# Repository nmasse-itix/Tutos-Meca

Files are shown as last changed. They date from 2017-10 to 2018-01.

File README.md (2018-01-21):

# Tutos mécanique
## Renault Avantime
### Trains roulants
- [Remplacement des triangles](Renault-Avantime/Remplacement-des-triangles/README.md)

### Habitacle
- [Démonter les panneaux de porte](Renault-Avantime/Demontage-des-panneaux-de-porte/README.md)
- [Réparation de la serrure, portière conducteur](Renault-Avantime/Reparation-de-la-serrure/README.md)

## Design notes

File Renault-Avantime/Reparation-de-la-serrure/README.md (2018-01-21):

# Réparation de la serrure de portière d'une Renault Avantime

## Symptômes

Parfois lorsque la télécommande qui permet de verrouiller/déverrouiller les portes
tombe en panne, plutôt que de faire réparer la télécommande, on utilise la serrure
pour ouvrir la portière.

Hé bien, c'est une bien mauvaise idée !

La serrure de l'avantime a l'air plutôt fragile de conception et pourrait bien vous
lâcher un jour ou l'autre.

Lorsque la serrure casse, le barillet vous reste dans les mains avec la clé et si
la serrure n'est pas déverrouillée, il n'est plus possible d'ouvrir la portière.

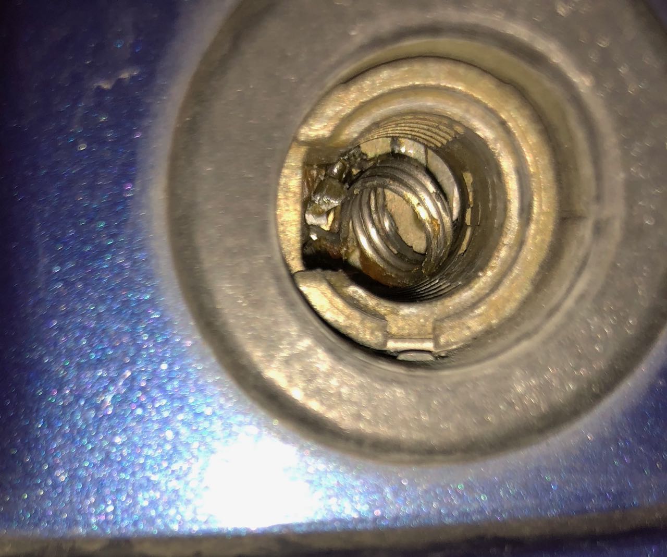
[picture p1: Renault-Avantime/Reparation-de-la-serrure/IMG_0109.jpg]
Voici ce qu'il reste de la serrure


Si vous avez encore la télécommande, ouvrez la portière avec celle-ci. Dans le cas
contraire, il faut ouvrir la portière comme le ferait un voleur...

Si heureusement la portière s'est déverrouillée avant de casser, vous avez de la
chance, il vous suffira de la réparer !

Le barillet ressemble à ça :

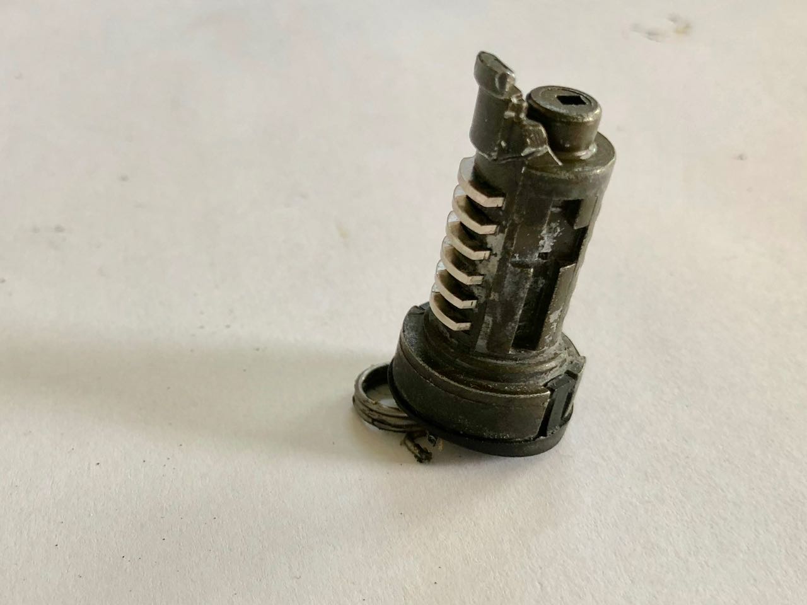
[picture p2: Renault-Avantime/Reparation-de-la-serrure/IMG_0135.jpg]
Le barillet


La petite pièce qui entraîne le mécanisme de la serrure est cassée :

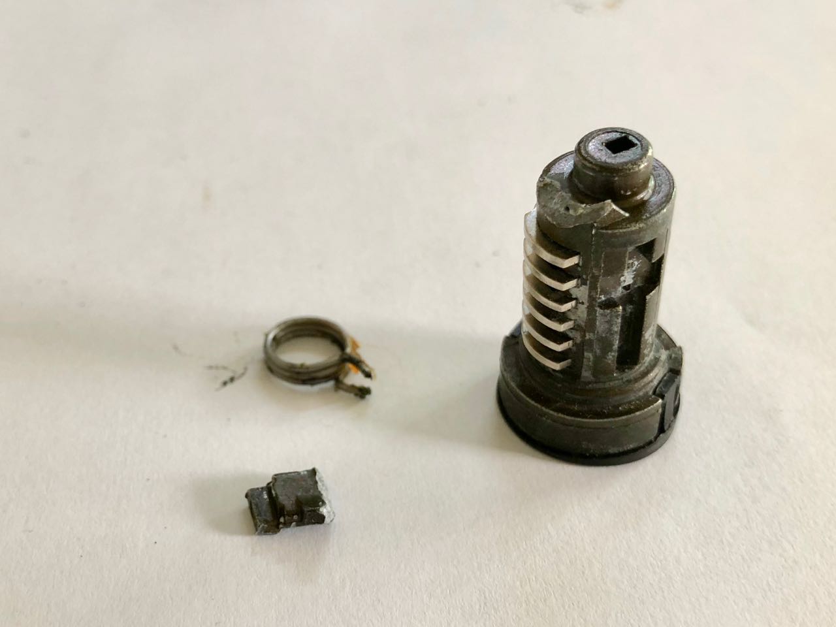
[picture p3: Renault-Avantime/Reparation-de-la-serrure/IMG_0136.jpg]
Le barillet cassé


## Matériel nécessaire

En plus du matériel nécessaire pour [démonter les panneaux de porte](../Demontage-des-panneaux-de-porte/README.md), il vous faudra :

- une Dremel
- une lime
- un pied à coulisse
- un marqueur fin
- un petit tournevis
- une pince à ressort pour tenir les pièces pendant le collage
- une toute petite pince étau pour tenir les pièces pendant le collage (ou pince équivalente)

## Liste des consommables à acheter

- de la colle bi-composant, type Araldite ou [Cyanolit Puissance +](https://www.cyanolit-colles.com/produits/colle-puissance-plus/).
- de l'huile grafitée pour serrures
- une bombe de nettoyant frein

## 1. Démontage

### 1.1. Démonter les panneaux de porte

[Démonter les panneaux de porte en suivant les instructions ici](../Demontage-des-panneaux-de-porte/README.md).

### 1.2. Démonter la platine qui tient la serrure

Une fois les panneaux de porte démontés, il faut enlever la vis qui tient la platine noire de la serrure.

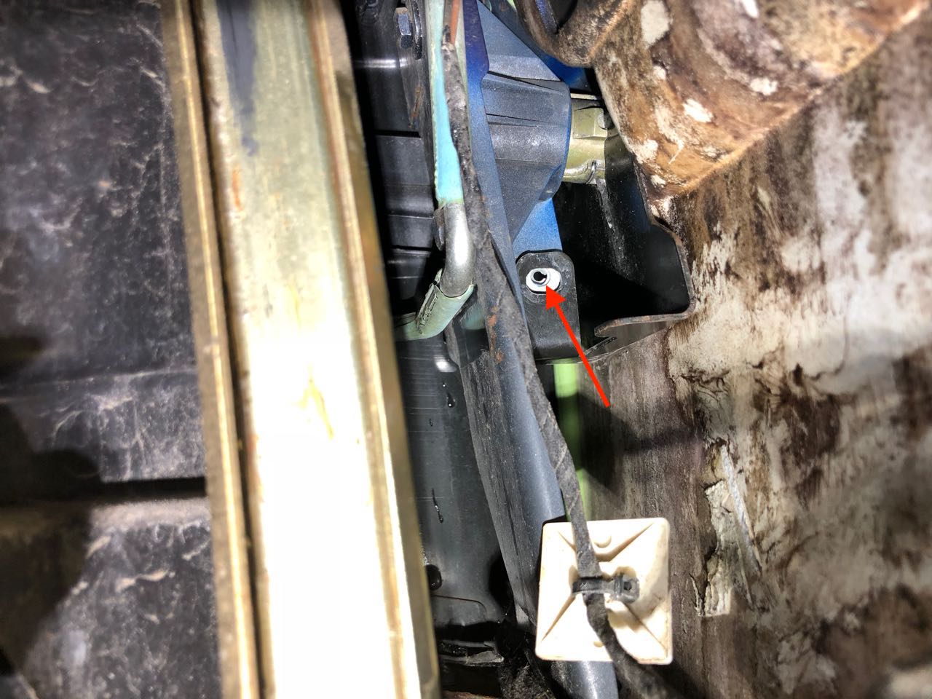
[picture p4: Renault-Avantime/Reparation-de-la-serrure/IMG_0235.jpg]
La platine et sa vis à enlever


Sortir la platine en la tirant vers le bas et en la penchant sur le coté.

La serrure sort à la main __par l'extérieur__.

## 2. Composition de la serrure et mode de fonctionnement

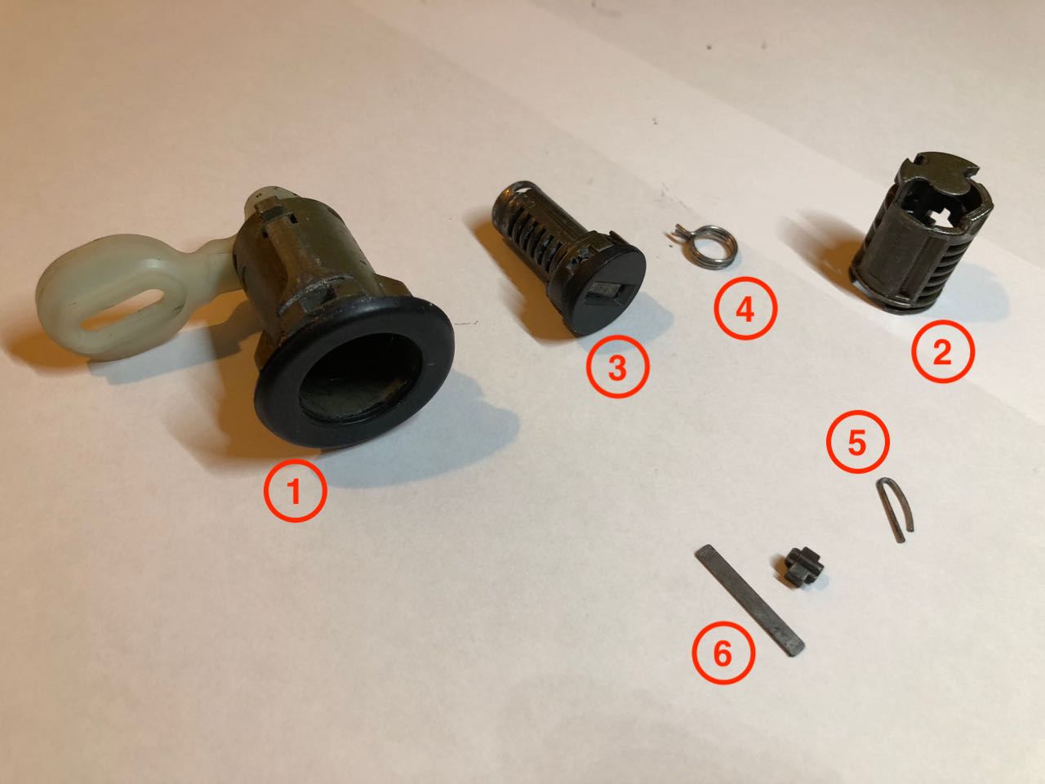
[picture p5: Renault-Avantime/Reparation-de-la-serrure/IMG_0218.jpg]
Les différentes pièces de la serrure


La serrure se compose des différentes pièces suivantes :

1. Corps de la serrure
2. Stator
3. Rotor ou barillet
4. Ressort de rappel
5. Goupille
6. Lame et pointeau

Le corps de la serrure accueille le stator et dispose en son fond d'un mécanisme de levier
pour actionner la gâche lorsque la clé est tournée.

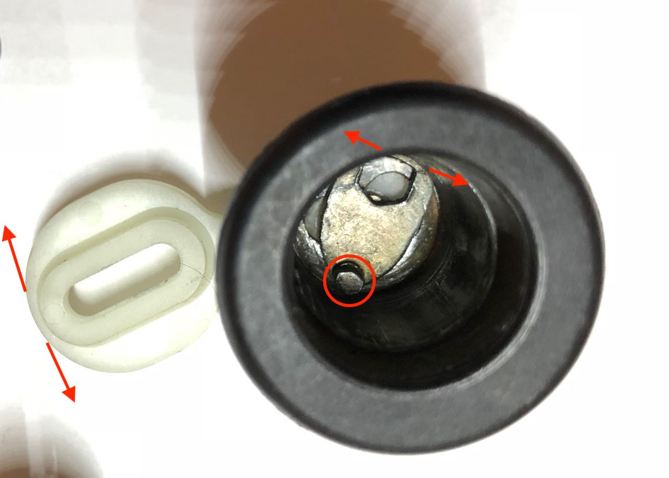
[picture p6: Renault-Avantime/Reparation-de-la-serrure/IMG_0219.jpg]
Le mécanisme de levier du corps de la serrure


Le mécanisme permet en actionnant l'oeil de faire bouger la gâche **si et seulement si
l'axe de rotation entouré en rouge sur la photo est maintenu fixe**. C'est une protection
pour éviter que quelqu'un forçant la serrure avec un tournevis ou un forceur ne puisse
actionner la gâche car dans ce cas l'axe de rotation tournerait en même temps que l'oeil,
et la gâche resterait fixe.

L'axe de rotation est maintenu fixe grâce au stator qui dispose d'un trou dans lequel vient
se loger l'axe de rotation du levier.

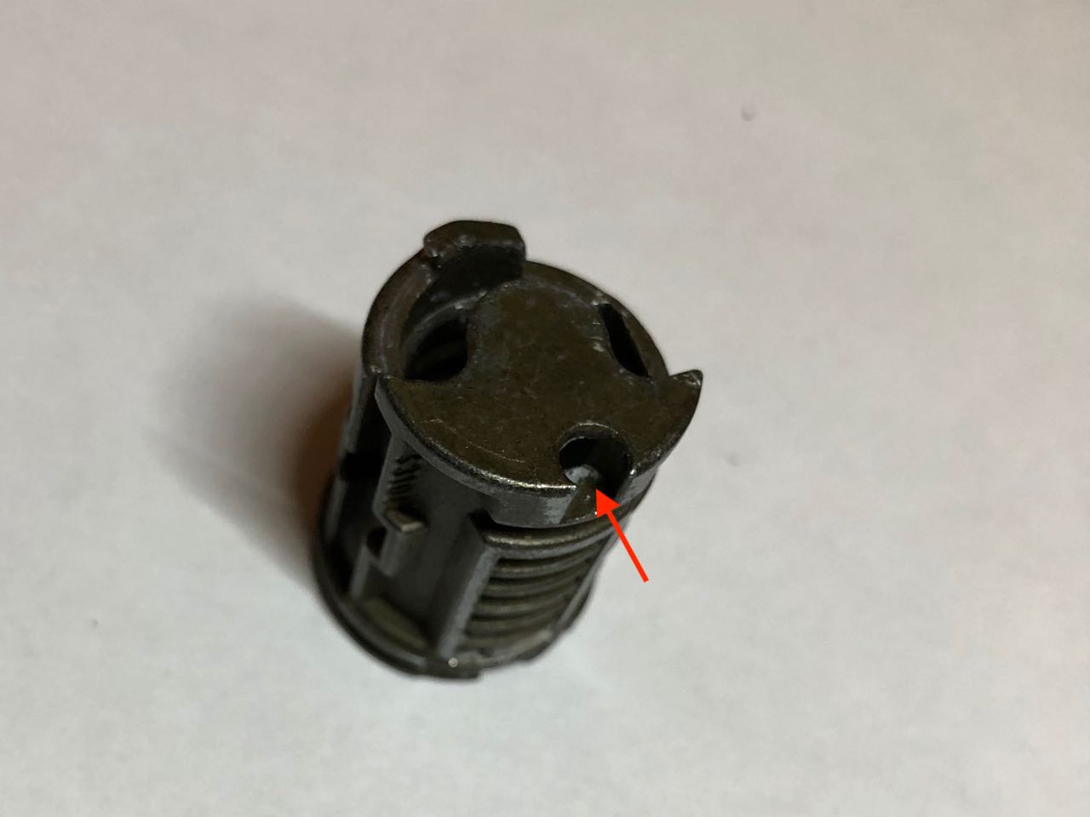
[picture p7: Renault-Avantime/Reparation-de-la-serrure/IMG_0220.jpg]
Le logement pour l'axe de rotation du levier


Le stator vient se positionner dans le corps de la serrure grace à un pointeau et une
lame qui joue le role de ressort.

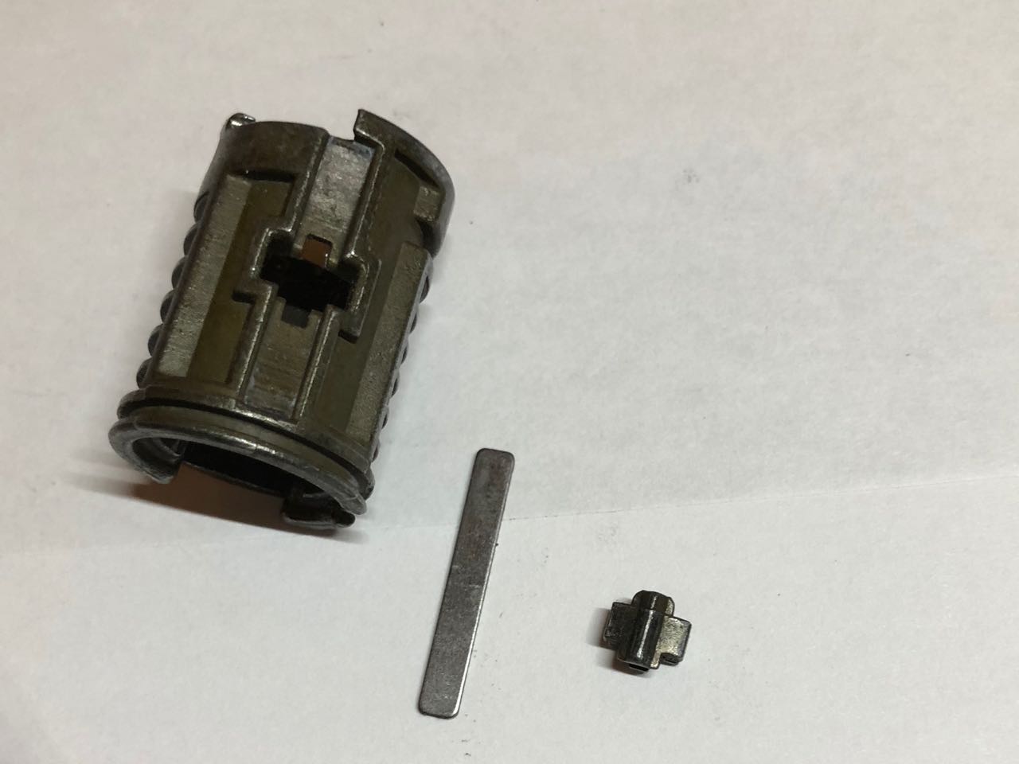
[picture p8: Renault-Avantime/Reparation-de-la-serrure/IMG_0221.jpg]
Le stator, le pointeau et la lame


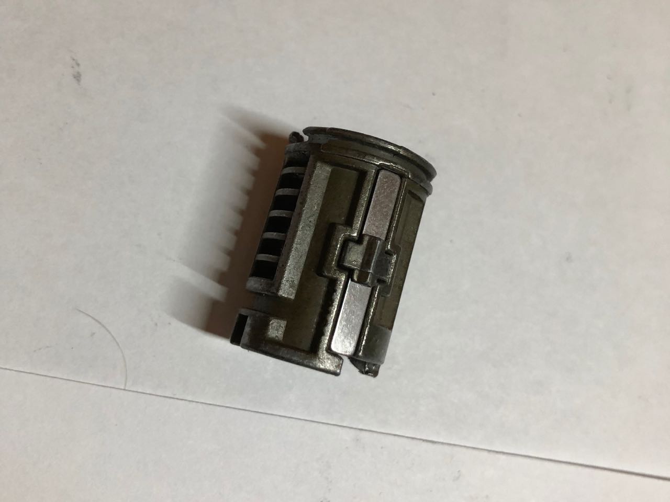
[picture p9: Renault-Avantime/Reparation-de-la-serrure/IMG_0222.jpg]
Le tout assemblé


Le corps de la serrure présente une rainure dans laquelle vient se placer le pointeau.

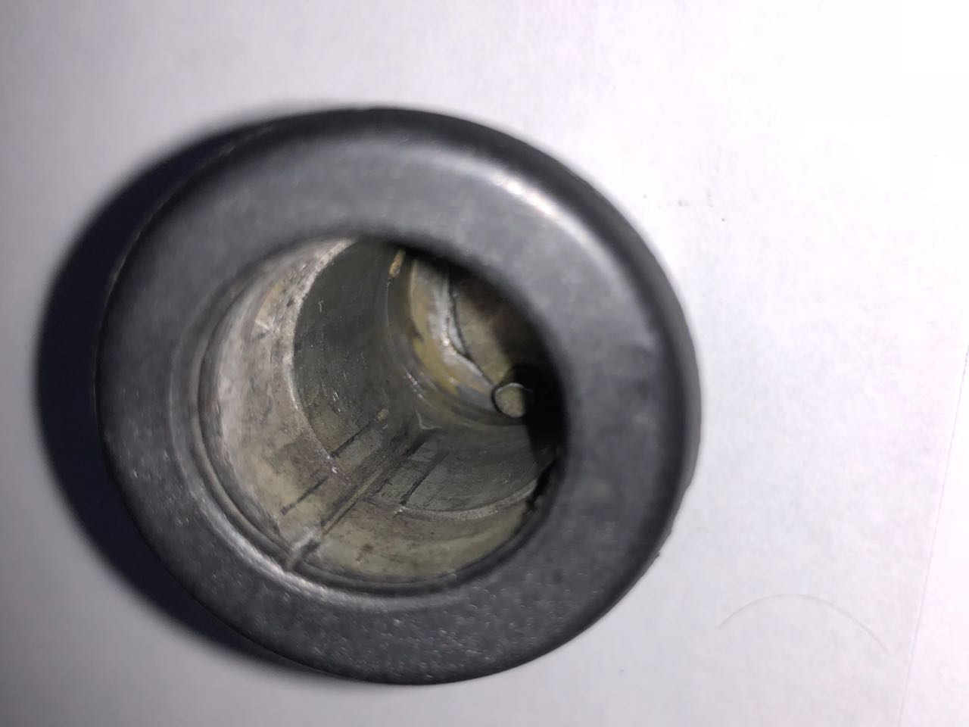
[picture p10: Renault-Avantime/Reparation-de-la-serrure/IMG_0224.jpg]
La rainure correspondante dans le corps de la serrure


Le rôle du pointeau est d'empêcher, lors du fonctionnement normal de la serrrure,
le barillet de tourner dans le corps de la serrure.
La lame, qui joue un rôle de ressort, permet de plaquer le pointeau dans la rainure et donc
dans les conditions normales d'utilisation le stator et le corps sont fixes.
L'intérêt d'un tel type de montage est de permettre au stator de tourner dans le corps
de la serrure lorsqu'un voleur tente de forcer la serrure.

Ainsi, les paillettes du barillet ne seront pas endommagées et vu que l'axe de rotation
du levier tournera en même temps que l'oeil du levier, la gâche restera fixe malgré la
rotation du stator dans le corps de la serrure.

Le stator est maintenu en place dans le corps de la serrure à l'aide d'une goupille.
La goupille vient s'insérer dans la rainure circulaire qui se trouve sur le pourtour
du stator.

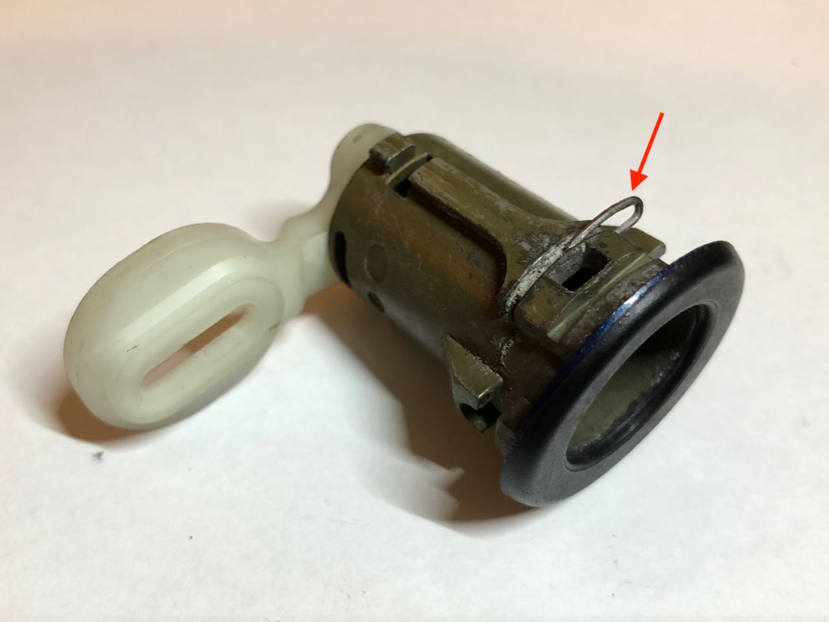
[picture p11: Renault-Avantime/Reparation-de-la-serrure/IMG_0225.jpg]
La goupille


Le stator peut ainsi tourner dans le corps de la serrure si celle-ci est en train
d'être forcée par un voleur mais ne peut pas sortir si on essaye d'arracher la serrure.

Le barillet vient s'insérer dans le stator. Les [paillettes](https://www.lockpickingfrance.org/serrures-a-pailletes.html)
permettent de rendre le barillet et le stator solidaires tant que la bonne clé
n'est pas insérée dans la serrure.

Le barillet

Un ressort de rappel permet de ramener le barillet dans sa position neutre. Les deux
pattes du ressort de rappel viennent se positionner de part et d'autre de la petite
patte du stator :

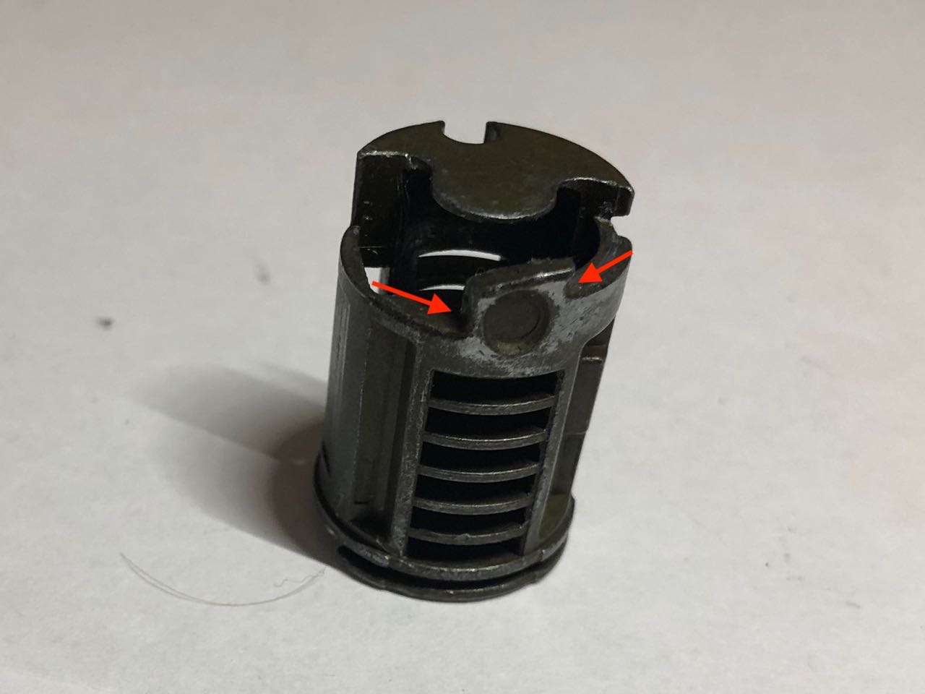
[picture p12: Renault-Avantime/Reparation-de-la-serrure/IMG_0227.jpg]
Le positionnement des pattes du ressort de rappel


## 3. Réparation de la partie cassée

Pour remplacer la partie cassée, nous allons fabriquer une petite pièce en métal qui viendra
prendre un appui plus large sur le barillet et qui devrait être plus solide.

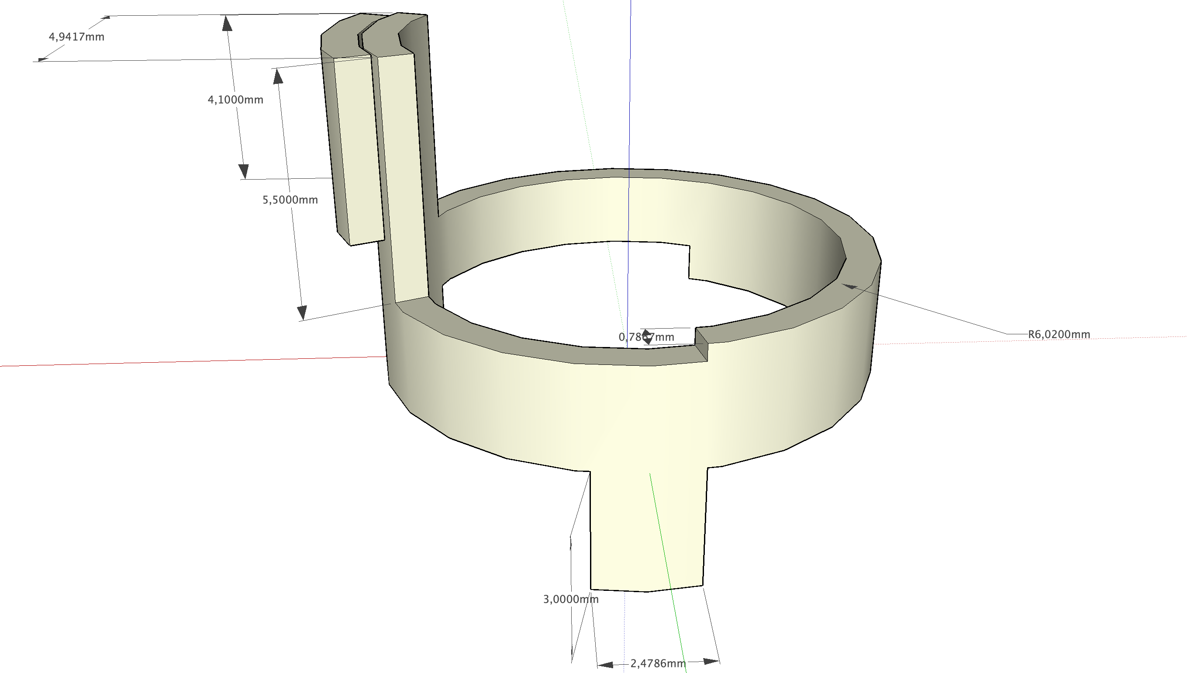
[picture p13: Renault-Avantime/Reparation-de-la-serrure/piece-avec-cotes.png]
La pièce à fabriquer avec les cotes


Le rôle de la petite patte dessous est de prendre appui sur le barillet pour transmettre le
mouvement de rotation du barillet à la gâche au moyen de notre petite pièce.

La grande patte en haut permet de transmettre le mouvement de rotation imprimé par le barillet
au levier qui est dans le corps de la serrure pour in fine actionner la gâche.

L'excroissance sur la patte en haut permet au barillet de ne pas sortir du stator lorsque l'on
retire la clé de la serrure.

Et les deux échancrures, sur le pourtour de part et d'autre de la grande patte, servent
à faire coulisser les deux pattes du ressort de rappel lorsque le barillet tourne.

[Le plan sketchup est disponible ici.](https://raw.githubusercontent.com/downloads/nmasse-itix/Tutos-Meca/master/Renault-Avantime/Reparation-de-la-serrure/piece.skp)

## 3.1. Matériel nécessaire

Pour fabriquer cette petite pièce, il vous faudra un morceau de tube métallique
de même diamètre que le corps du barillet (12mm). Le matériaux le plus facilement et le plus
largement disponible pour cet usage est le tube de cuivre écroui pour la plomberie.

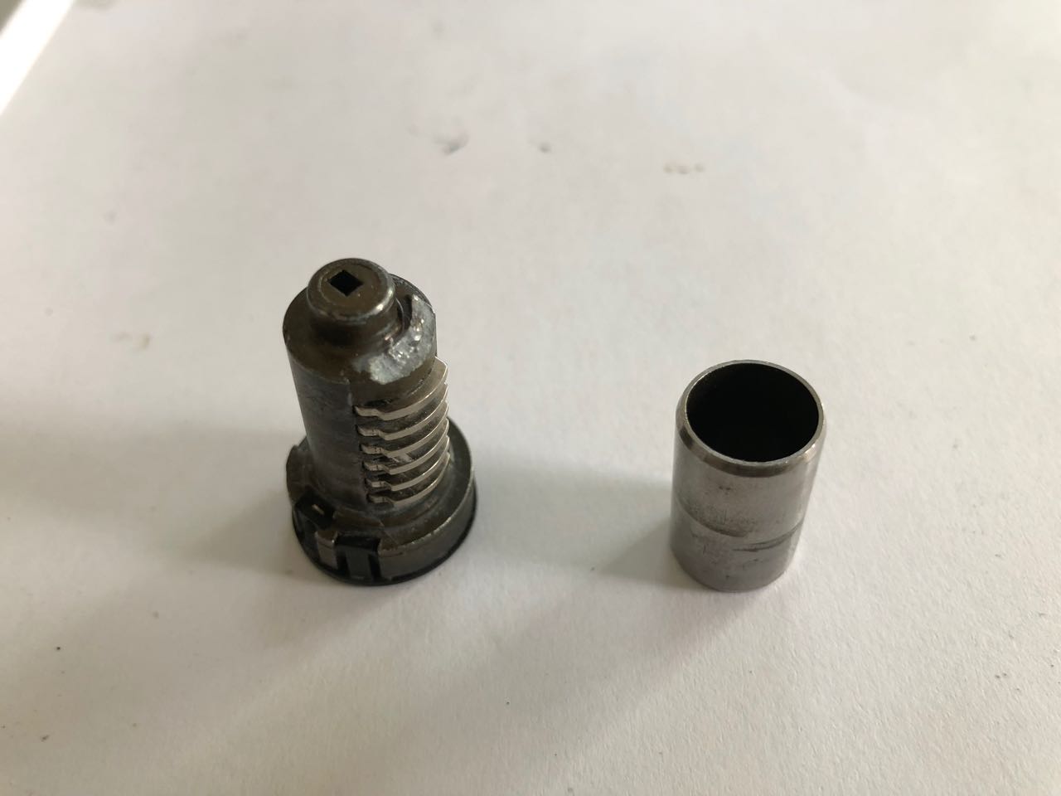
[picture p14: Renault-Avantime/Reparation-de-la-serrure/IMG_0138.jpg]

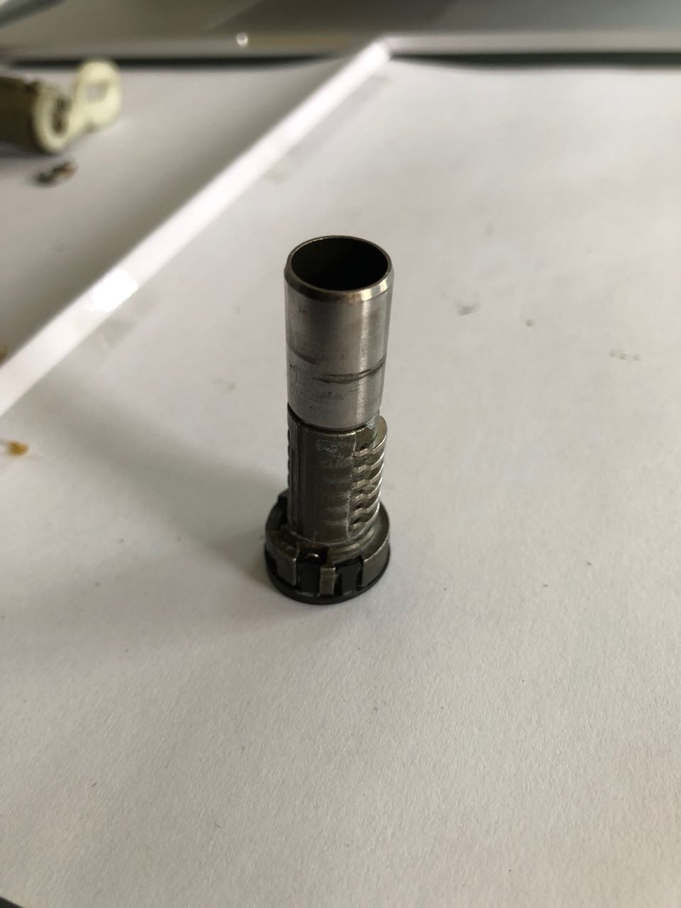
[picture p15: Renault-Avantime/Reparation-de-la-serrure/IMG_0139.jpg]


Pour ma part, j'avais dans ma réserve de pièce une petite entretoise en acier du bon diamètre.
J'ai opté pour cette solution.

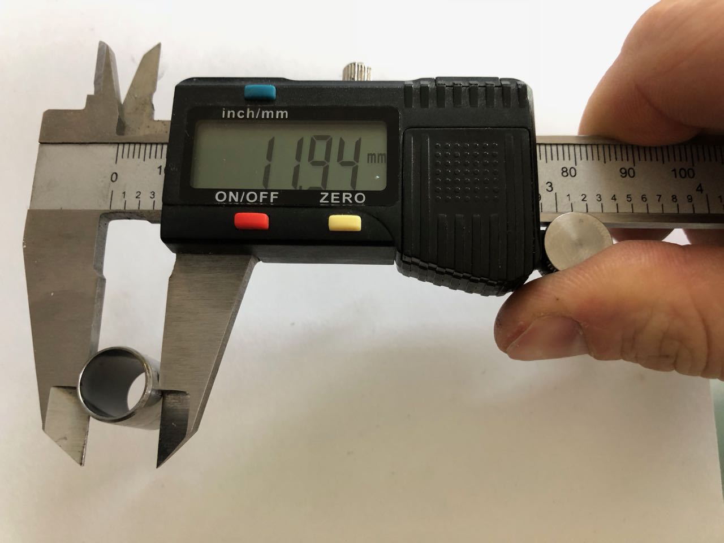
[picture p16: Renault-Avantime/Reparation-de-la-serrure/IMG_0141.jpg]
Diamètre 11,94 mm

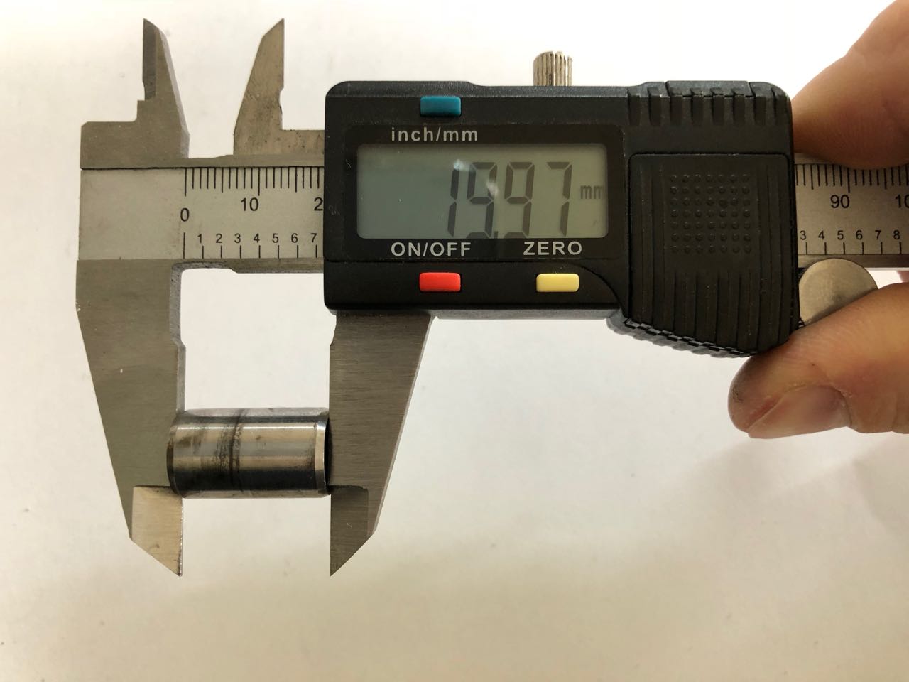
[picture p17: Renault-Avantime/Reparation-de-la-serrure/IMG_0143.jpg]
Longueur 20 mm


## 3.2. Préparation du barillet

Afin de permettre à la petite patte de notre pièce de prendre appui sur le barillet,
il faut prolonger la rainure existante sur le barillet jusqu'au bout.

Pour cela, utiliser une dremel. Le barillet avant:

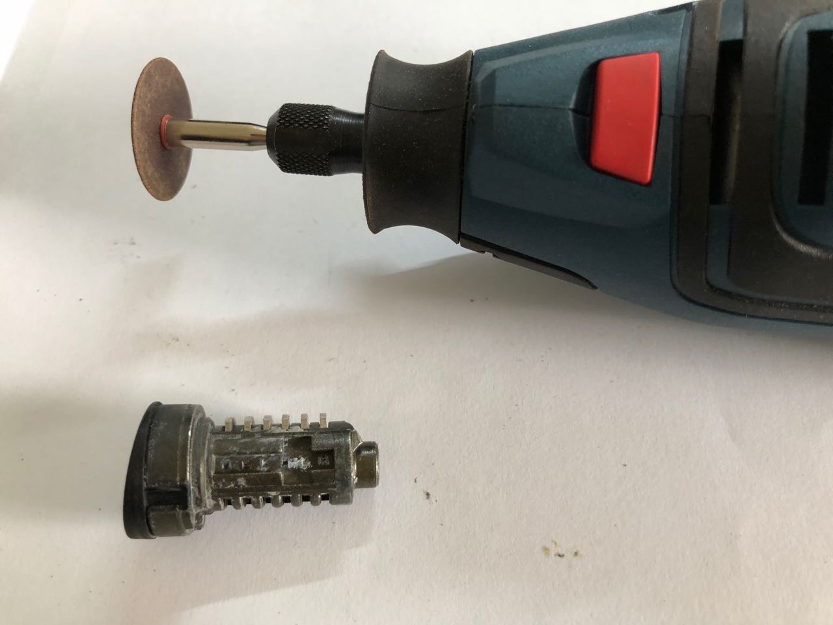
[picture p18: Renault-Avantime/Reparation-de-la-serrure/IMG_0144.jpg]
Le barillet avant


Le barillet après :
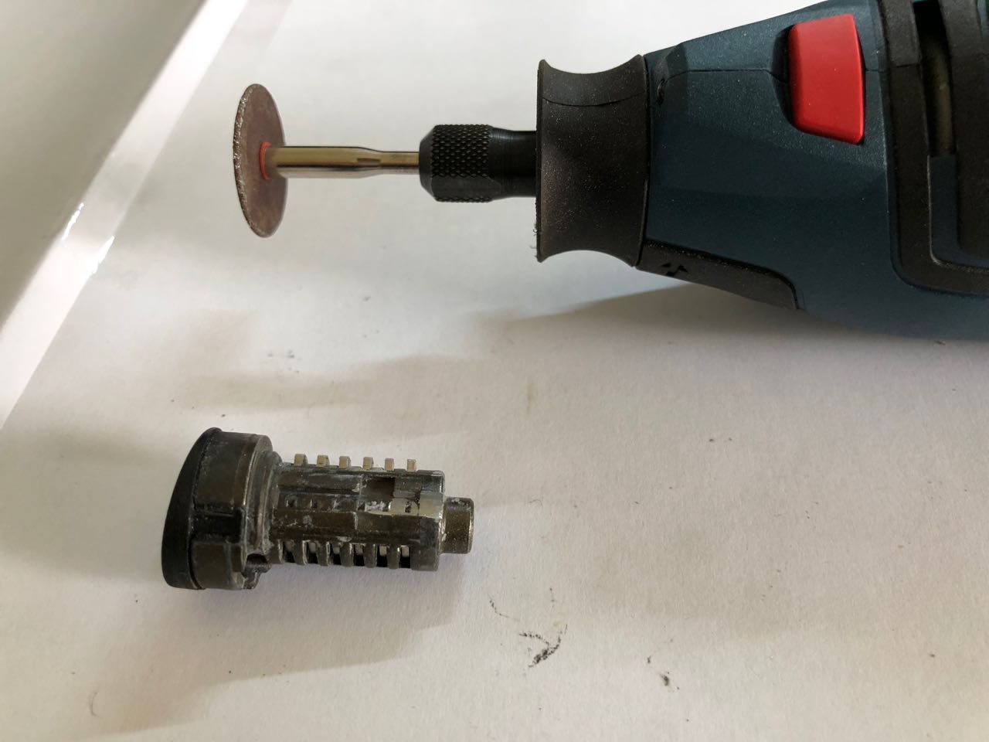
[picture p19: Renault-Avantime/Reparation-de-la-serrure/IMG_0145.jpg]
Le barillet après


En profiter également pour nettoyer l'endroit de la cassure à la dremel...

## 3.3. Réalisation de la petite patte

A la dremel, découper le tube pour réaliser la petite patte, de hauteur 3mm et de
même largeur que la rainure réalisée dans le barillet (environ 2,5mm).

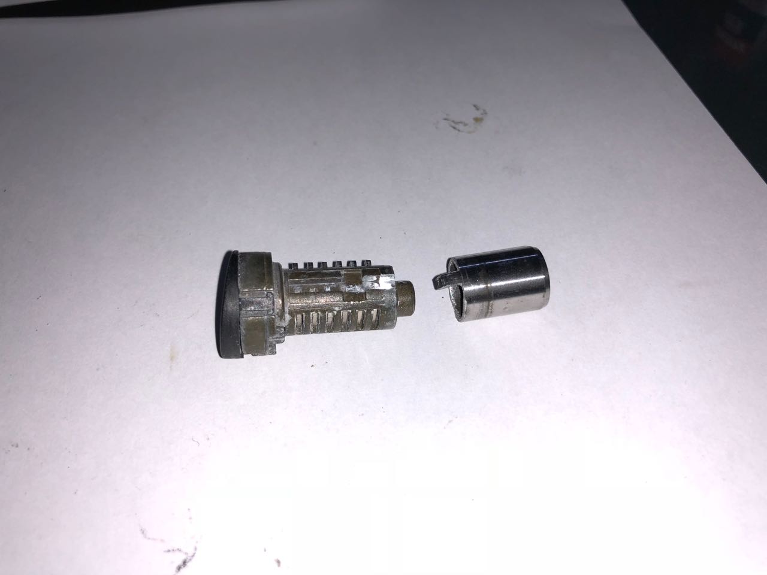
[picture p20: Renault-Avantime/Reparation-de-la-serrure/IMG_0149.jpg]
Le barillet et la petite patte sur la pièce


## 3.3. Réalisation de la grande patte

Tracer sur la pièce les cotes de la grande patte (largeur, hauteur). **Attention
à l'orientation des deux pattes dans l'espace.** Les milieus des deux pattes sont
séparés d'un quart de tour. Se référer à la photo pour repérer le sens !

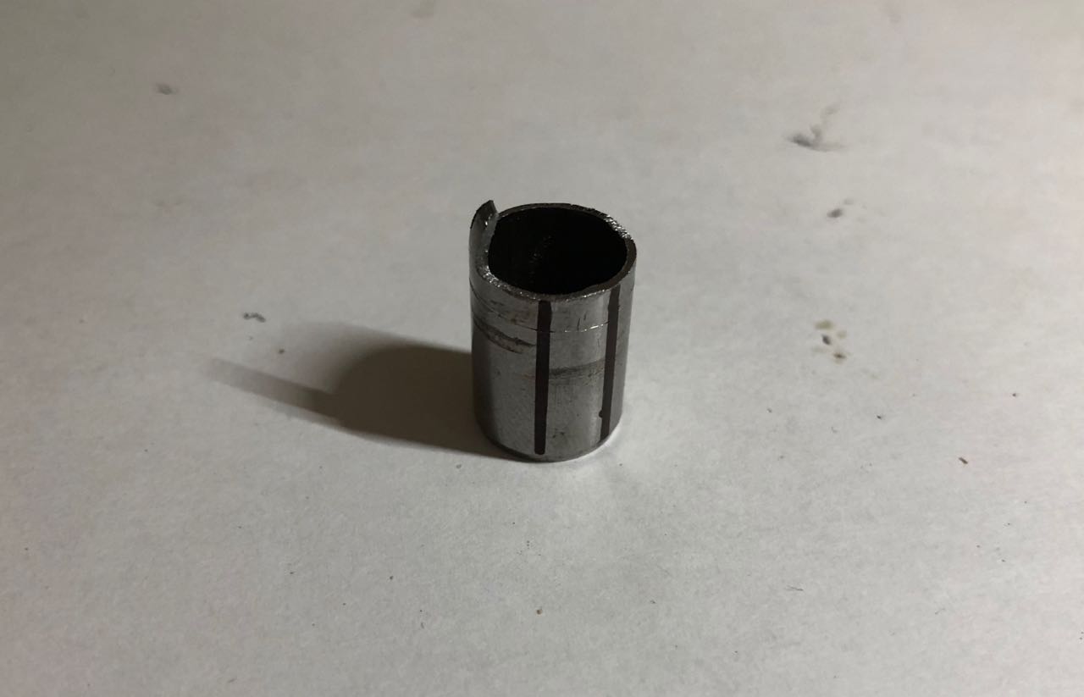
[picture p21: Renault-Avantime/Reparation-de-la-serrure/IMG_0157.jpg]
Les cotes tracées


Sur la photo, la largeur (4.8mm) a été tracée au marqueur fin et la hauteur a été tracée
au trusquin.

Découper à la dremel la grande patte.

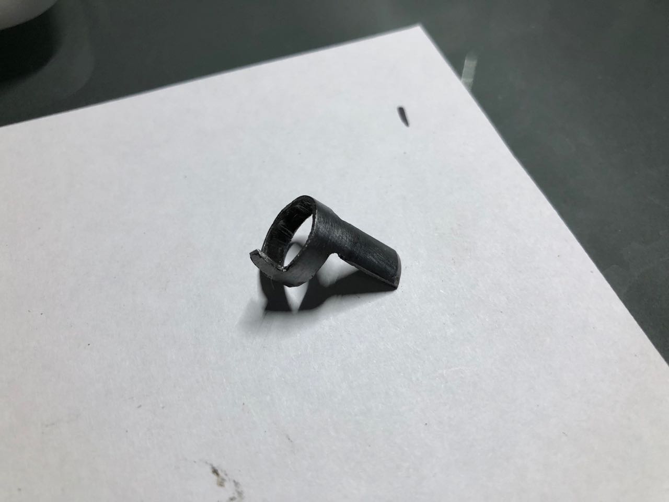
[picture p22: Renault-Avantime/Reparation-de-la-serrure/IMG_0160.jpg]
La grande patte


## 3.4. Réalisation des deux échancrures

Réaliser les deux échancrures de chaque coté de la grande patte, sur le pourtour de la pièce,
pour l'une en dessous de la pièce et pour l'autre, au dessus.

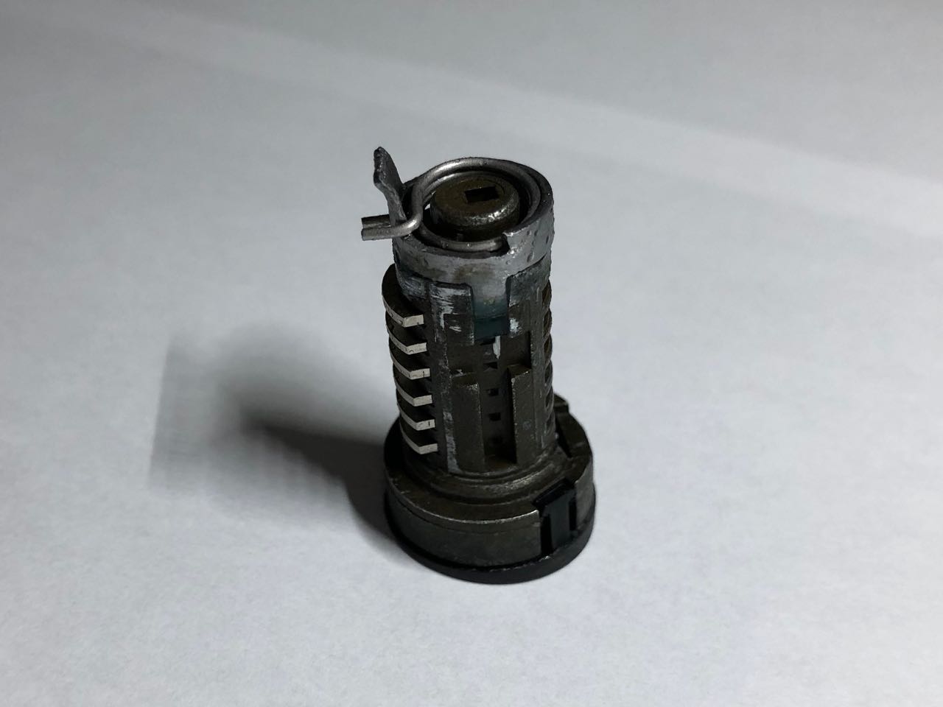
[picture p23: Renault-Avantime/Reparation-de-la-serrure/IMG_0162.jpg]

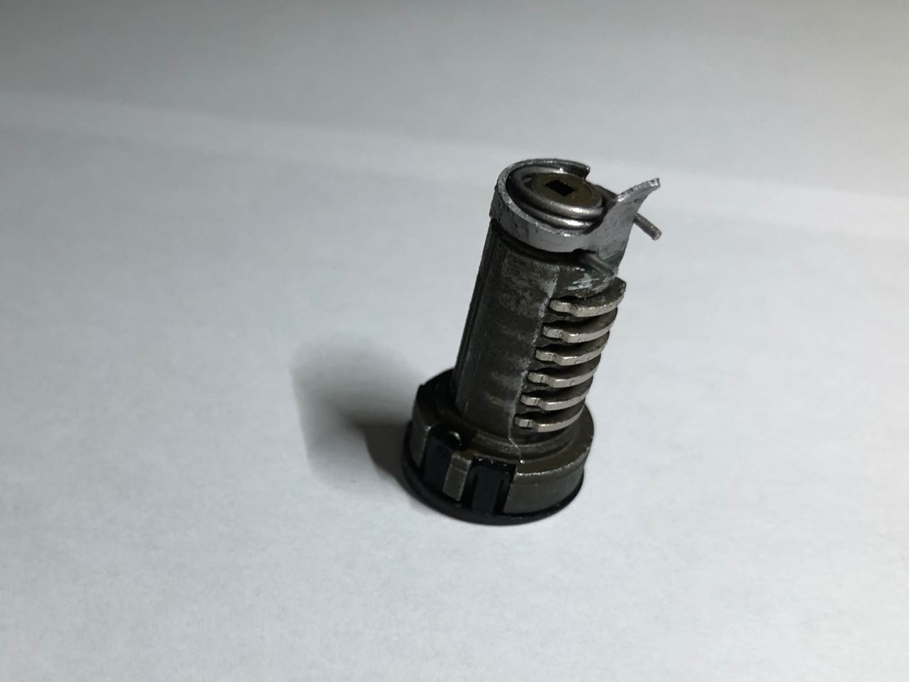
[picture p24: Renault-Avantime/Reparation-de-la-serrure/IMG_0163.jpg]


Se référer au plan pour ne pas se tromper de dimension ! Découper les échancrures à la Dremel.

## 3.5. Collage de la pièce sur le barillet

La pièce réalisée doit être solidaire du barillet, c'est pourquoi il est nécessaire de réaliser un collage.

Les endroits à coller sont :

 - la petite patte (collée avec la rainure dans le barillet)
 - tout le pourtour inférieur de la pièce, échancrure exclue (collée avec le pourtour du barillet)

La première étape du collage est de réaliser un chanfrein sur le pourtour de la pièce et le pourtour du barillet
afin d'augmenter la surface de contact et d'avoir une bonne accroche. Utiliser la Dremel pour cela.

Pour le collage en lui-même, utiliser une colle bi-composant de type Araldite ou Cyanolit.
Bien dégraisser la pièce et le barillet avant, à l'aide d'une bombe de nettoyant frein.
Maintenir les pièces pendant le collage (24h à 48h) à l'aide d'une pince à ressort.

Une fois le collage sec, éliminer les sur-épaisseurs à l'aide d'une lime.

## 3.6. Réalisation de l'excroissance sur la grande patte

Dans une des chûtes de tube, découper une petite pièce carrée de hauteur 4mm et de
même largeur que la grande patte (4.8mm).

## 3.7. Collage de l'excroissance sur la grande patte

L'excroissance doit être collée sur la grande patte pour permettre au barillet de
rester en place lorsque l'on retire la clé de la serrure.

Pour cela, l'excroissance doit être collée en position, barillet dans le stator :

 - Insérer la clé dans le barillet
 - Insérer le tout dans le stator
 - Aligner la grande patte avec la patte du stator (où viennent se loger les deux pattes du ressort de rappel)
 - Retirer la clé du barillet

Une fois la clé retirée, les paillettes retiennent le barillet et le stator dans la bonne position.

Il faut alors coller l'excroissance sur notre pièce de telle manière qu'elle vienne
reposer sur la patte du stator:

L'excroissance collée sur la grande patte, en position sur le stator

Pour le collage en lui-même, utiliser une colle bi-composant de type Araldite ou Cyanolit.
Bien dégraisser la pièce et le barillet avant, à l'aide d'une bombe de nettoyant frein.
Maintenir les pièces pendant le collage (24h à 48h) à l'aide d'une petite pince étau
(ou petite pince à ressort).

**Faire bien attention à ne pas coller le barillet et le stator ensemble !**

Une fois le collage sec, éliminer les sur-épaisseurs à l'aide d'une lime.

## 3.8. Remontage de la serrure

Pour le remontage, procéder ainsi :

1. Déposer un peu d'huile grafitée aux endroits de friction : sur le pourtour de
   la pièce, à l'extrémité de la grande patte, sur les deux échancrures
2. Déposer le ressort de rappel sur le bout du barillet
   Le ressort de rappel au bout du barillet
3. Mettre la clé dans le barillet
4. Insérer le barillet dans le stator (attention, il y a une position pour le rentrer
   maintenant que l'excroissance à été collée)
5. Au bout du stator, récupérer la patte supérieure du ressort de rappel avec
   un petit tournevis et la positionner de l'autre coté de la grande patte.
   La patte supérieure du ressort de rappel
   La patte supérieure du ressort de rappel bien positionnée
6. Enfoncer à fond le barillet dans le stator
7. Récupérer à nouveau la patte supérieure du ressort de rappel avec
   un petit tournevis et la positionner de l'autre coté de la patte du stator.
   La patte supérieure du ressort de rappel bien positionnée
8. Vérifier que la clé rentre et sort librement sans accrocher.
9. Vérifier que la clé peut tourner d'un coté et de l'autre et qu'elle revient
   en place toute seule. Vérifier qu'en position neutre (position imprimée par
   le ressort de rappel), la clé sort librement.
10. Positionner la lame et le pointeau dans leur emplacement (la lame est dans
    le pointeau et **attention, la lame à un sens lié à sa courbure**)
    La lame et le pointeau en place
11. Positionner à l'aide d'un petit tournevis l'axe du levier dans le corps de la
    serrure. Lorsqu'il est en position, il doit être visible par la petite fenêtre
    sur le coté. Positionner l'oeil du levier bien en face.
    Le l'axe positionné en face de la fenêtre
12. Enfoncer l'ensemble barillet-stator-lame-pointeau dans le corps de la serrure,
    le pointeau bien aligné avec sa rainure.
13. Mettre la goupille en place
14. Remettre la clé et vérifier que la serrure fonctionne.

## 3.9. Dernières remarques

L'excroissance collée n'est pas strictement nécessaire. En effet, le barillet tient
assez bien tout seul à l'aide des pattes du ressort de rappel. En revanche, dans
ce cas la précision d'assemblage n'est pas suffisante pour permettre à la clé de sortir
(les paillettes du barillets ne s'alignent pas avec les trous du stator), il faut
alors tenir le barillet pour pouvoir sortir la clé.

# 4. Remontage

La serrure s'insère par l'extérieur en faisant attention à bien aligner le trou
de la gâche avec le pion qui est sur le levier dans la portière.

Les deux éléments à aligner

Remettre la platine noire qui tient la serrure, par l'intérieur de la portière et
la refixer avec sa vis.

La platine noire et sa vis

[Le reste du remontage s'effectue à l'inverse de la dépose comme décrit ici.](../Demontage-des-panneaux-de-porte/README.md)

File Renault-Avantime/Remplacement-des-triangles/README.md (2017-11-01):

# Remplacement des triangles sur une Renault Avantime

## Symptômes
Les triangles sont à changer quand :
- vous entendez un bruit sourd à la descente d'un dos d'âne
- vous entendez un "cloc-cloc" lorsque vous freinez légèrement à basse vitesse
- ça vibre dans le volant quand vous accélérez fortement ou au freinage
- le contrôle technique signale un jeu important sur le demi-train avant

## Matériel nécessaire
En plus du matériel courant, les outils suivants sont nécessaires :
- une grande rallonge d'un mètre pour désserrer les écrous bien serrés
- une clé dynamométrique (plage 25 à 210 N.m)
- deux clés/douilles de 22 **à 12 pans**. C'est très courant, les douilles classiques 6 pans ont déjà en général 12 pans. Chez Facom la référence est `S.22`. Dans le cas présent, j'avais une douille Magnusson de 22 et une clé à pipe Facom de 22 également.
- un jeu de chasses rotules à frapper (références `670.0091`, `670.0092` et `670.0094` chez KS.Tools)

**Note: Se faire aider d'une deuxième personne n'est pas du luxe.**

## Liste des pièces à acheter

- Un triangle coté conduteur (référence RENAULT : 6025305572 - 6025307649, moi jj'ai opté pour le [TRW JTC1095](https://www.oscaro.com/triangle-de-suspension-trw-jtc1095-1857579-273-p))
- Un triangle coté passager (référence RENAULT : 6025305573 - 6025307650, moi j'ai opté pour le [TRW : JTC1094](https://www.oscaro.com/triangle-de-suspension-trw-jtc1094-1857578-273-p))
- Deux boulons de 22 (référence RENAULT : 8201084688)
- Deux écrous de 22 (référence RENAULT : 7700802227)

**Note: Les écrous et boulons de 18 qu'il faudrait en théorie remplacer à chaque changement de triangle ne sont plus fabriqués par Renault.**

## Mode opératoire

### 1. Lever et mettre le véhicule sur chandelles

Il est impératif de lever **les deux roues** du véhicule, même si vous ne changez qu'un coté. En effet, il faudra déconnecter la biellette de barre stabilisatrice et vous ne pourrez pas le faire si une des roues repose encore sur le sol.

Vous pouvez placer les chandelles sur les longerons, en intercalant une petite planche de bois pour ne pas marquer :

Placement des chandelles

### 2. Déposer la roue

Désserrer les écrous de roue et déposer la roue.

Une fois la roue déposée

On peut voir l'un des *silent block* du triangle dans un état moyen. Pour le triangle gauche et droit, c'est le *silent block* du fond, celui qui est caché, qui était le plus abimé.

On aperçoit le silent block

### 3. Déconnecter la biellette de barre stabilisatrice

La biellette est connectée en haut à l'amortisseur et en bas à la barre anti-roulis. Utiliser une clé plate de 17 et une clé BTR pour l'empêcher de tourner.

Déposer la biellette.

La fixation haute de la biellette

### 4. Détacher le cable du capteur ABS et le flexible de frein

Détacher le câble du capteur ABS et le flexible de frein. Ils sont clipsés sur le pied de l'amortisseur.

Déclipsez le câble et le flexible

### 5. Dévisser les deux vis du pied de l'amortisseur

Utilisez une douille de 24 et la rallonge car c'est serré fort !

Une fois dévissé...

### 6. Sortir l'amortisseur

Cette étape est optionnelle mais vu la facilité à sortir l'amortisseur une fois arrivé là et la place libérée, c'est une bonne option.

Dévisser les trois vis qui tiennent la tête de l'amortisseur. Elles sont dans le compartiment où se trouve le fitre habitacle (coté gauche, c'est derrière les bras d'essuie glace).

Utiliser une douille de 13 et un (petit) cliquet.

Dévisser les trois vis qui tiennent l'amortisseur...

Sortir l'amortisseur.

En profiter pour accrocher la fusée à un fil de fer pour éviter qu'elle ne bascule / tombe.

Attacher la fusée avec un fil de fer ou une ficelle

### 7. Démonter la rotule de suspension

La rotule de suspension est au bout du triangle. L'écrou est pris en sandwich entre le triangle et la couronne du capteur ABS. Faire extrèmement attention à ne pas abîmer la couronne.

Dévisser l'écrou de la rotule de suspension

L'écrou se dévisse avec une clé plate de 18 (et se remonte avec une clé de 19...).

Une fois l'écrou désserré, pour le sortir complètement il faut décoller la rotule. Utiliser pour cela un chasse rotule à frapper.

Décoller la rotule à l'aide du chasse rotule à frapper

Une fois décollée, la rotule tournera librement. Pour finir de dévisser son écrou, il faut la maintenir à l'aide d'une pince étau. **Attention: sur un des deux triangles, l'écrou était monté au frein filet. Il nous a fallu une grosse pince étau pour tenir correctement la rotule.**

Utilisation de la pince étau pour bloquer la rotule

Lever la fusée pour dégager la rotule.

### 7. Dévisser les deux fixations du triangle

Le triangle est maintenu par deux fixations (A et B sur le schéma ci-dessous). **Attention, la fixation arrière est un peu contre-intuitive: il s'agit du même boulon qui tient la barre anti-roulis**.

Fixations du triangle

Fixation de devant: utiliser la douille/clé de 22 pour bloquer l'écrou et l'autre clé/douille de 22 pour désserrer (en utilisant la rallonge, c'est serré fort).

Fixation de devant du triangle

Fixation de derrière: même mode opératoire mais avec la clé/douille de 18.

Fixation de devant du triangle

Le triangle sort sans problème par devant.

### 8. Remontage du nouveau triangle

Positionner le nouveau triangle de la manière suivante :
 - Positionner grossièrement le triangle
 - Insérer la vis de la rotule dans la fusée et visser sommairement l'écrou
 - Aligner la fixation avant avec le trou avant, insérer le boulon de 22 (neuf), par le dessus. Ne pas mettre l'écrou tout de suite, pour se garder un peu de jeu.
 - Aligner la fixation arrière avec le trou arrière et insérer le boulon de 18, par le dessous. **Note: monter-descendre le couple triangle-fusée peut aider.**

 - Visser l'écrou de 18 par le dessus
 - Positionner l'écrou de 22, tapotter avec un maillet pour qu'il rentre dans son logement. **Note: monter-descendre le couple triangle-fusée peut aider.**
 - Serrer le boulon de 18, l'écrou de 22 au couple. **Il faut le faire maintenant car quand l'amortisseur sera remonté, le triangle sera en effort et le boulon de 18 ne pourra plus être serré au couple** (ça a encore été bien conçu ce truc là).
 - Serrer l'écrou de fixation de la rotule. Il n'est pas possible d'y passer la clé dynamométrique donc c'est un serrage approximatif.

La suite du remontage s'effectue à l'inverse de la dépose.

Couples de serrage des fixations du triangle :
 - écrou de 22: **210 N.m**
 - écrou de 18: **120 N.m**

Le pied de l'amortisseur est à serrer à **200 N.m**, les trois vis qui tiennent le haut de l'amortisseur sont a serrer à **25 N.m** et les écrous de la biellette de barre stabilisatrice sont à serrer à **40 N.m**.

La totalite des couples de serrage sont listés ici en daN.m :

Couples de serrage

### 9. Vérifications

Avant de prendre la route, vérifier que :
 - les fixations du triangle sont serrées au couple
 - les vis du pied de l'amortisseur sont serrées au couple
 - l'écrou de la rotule est vissé et correctement serrée
 - les deux écrous de la biellette de barre stabilisatrice sont serrés au couple
 - les écrous qui tiennent le haut de l'amortisseur sont serrés au couple
 - le flexible de frein et le câble du capteur ABS sont re-fixés sur le pied de l'amortisseur
 - les écrous de roue sont correctement serrés
 - les disques de frein sont propres et dégraissés (si vous avez manipulé la fusée avec vos mains pleines de cambouis, il faut y passer un coup de dégraissant frein)

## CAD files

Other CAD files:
Renault-Avantime/Reparation-de-la-serrure/piece.skp

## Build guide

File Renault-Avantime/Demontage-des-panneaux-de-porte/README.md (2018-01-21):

# Démontage des panneaux de porte sur une Renault Avantime

## Matériel nécessaire
Les outils suivants sont nécessaires :

- clés torx de 20 et 30  
- un petit tournevis plat (0.4 x 2.5)
- un gros tournevis plat
- une spatule / un couteau de peintre
- une clé à pipe / douille de 10
- un petit pot pour mettre les vis au fur et à mesure du démontage
- un pistolet à cartouche

## Liste des consommables à acheter

- Une cartouche de colle [SikaLastomer-710](https://fra.sika.com/fr/groupe/publications/technologie-sika/butyles/sikalastomer--710.html)

## Démontage

### 0. Avertissement

Une fois les panneaux de portière démontés, le mécanisme du lève vitre sera accessible sans protection.
Il y a un risque de perdre un doigt si le lève vitre est activé et que vos doigts trainent quelque part sur le mécanisme.

**Dès lors, il est fortement recommandé de débrancher la batterie avant de commencer à démonter les panneaux de porte.**

Pensez juste à ouvrir les portes avant de débrancher la batterie car celles-ci ne peuvent s'ouvrir que lorsque la batterie est branchée !

### 1. Déposer les 4 vis du bas de porte

Il y a quatre vis torx à dévisser.

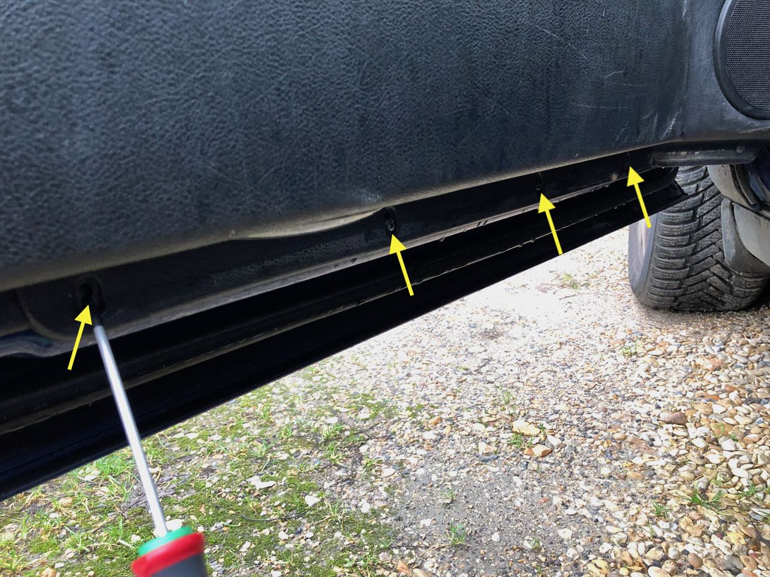
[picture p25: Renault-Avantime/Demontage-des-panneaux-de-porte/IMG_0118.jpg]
Quatre vis torx à dévisser en bas de portière


### 2. Déposer la poignée de porte

Il faut enlever le cache de la poignée de porte avec un petit tournevis plat ou à la main car il est juste clipsé.

Dévisser les deux boulons de 10 à l'aide d'une clé à pipe ou douille.

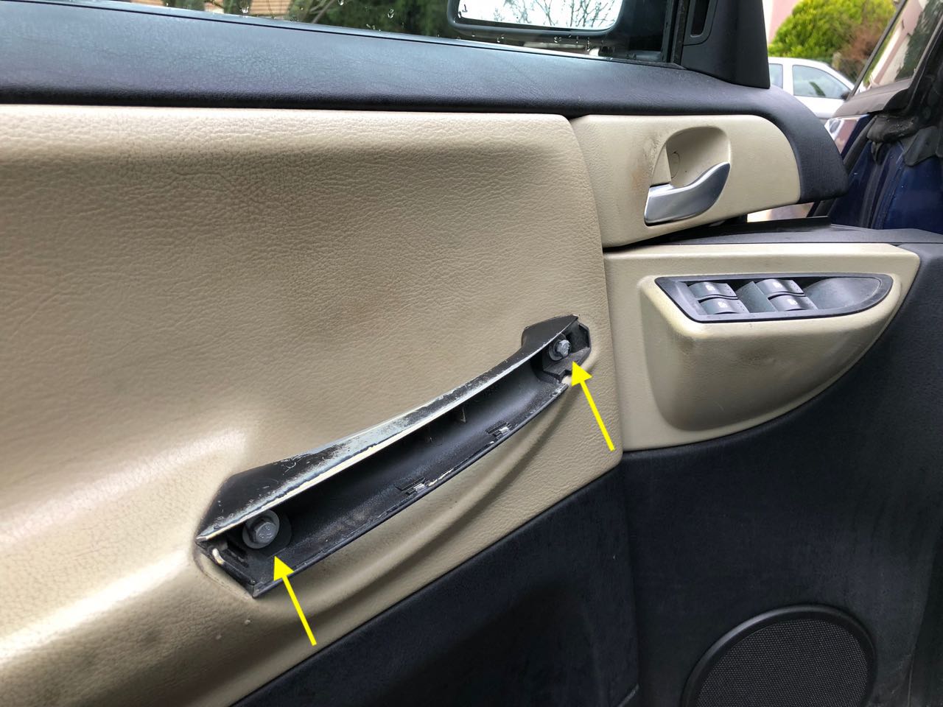
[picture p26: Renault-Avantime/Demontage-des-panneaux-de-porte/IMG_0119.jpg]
Les deux boulons à dévisser, une fois le cache enlevé


### 3. Déposer le cache trianglulaire

Il y a une vis torx sur le dessus et il vient ensuite à la main.

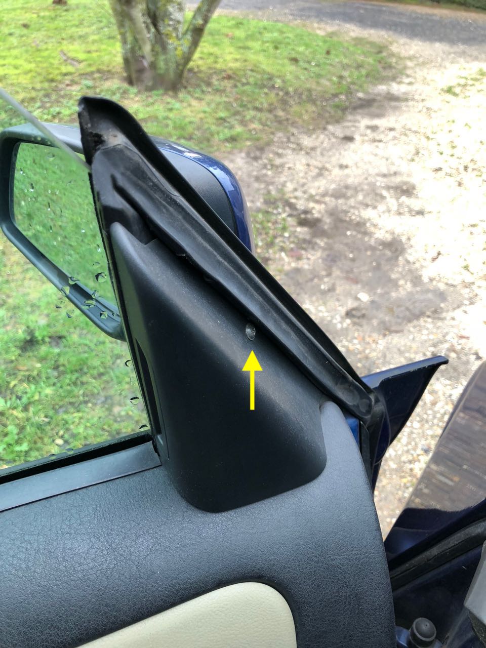
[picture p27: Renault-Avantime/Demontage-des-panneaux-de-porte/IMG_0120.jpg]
La vis à enlever


### 4. Déposer le cache de la poignée de porte

Il faut enlever délicatement le cache-vis rond à l'aide d'un petit tournevis plat et devisser la vis torx qui est derrière.

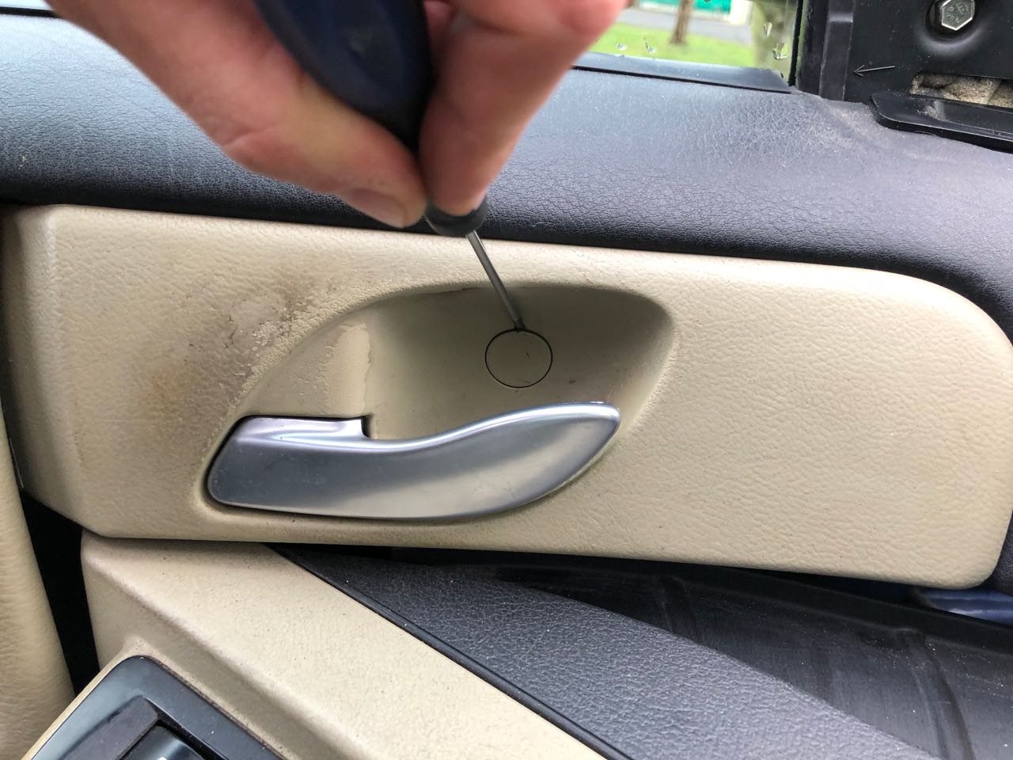
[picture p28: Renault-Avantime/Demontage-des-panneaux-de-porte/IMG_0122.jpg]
Enlever le cache

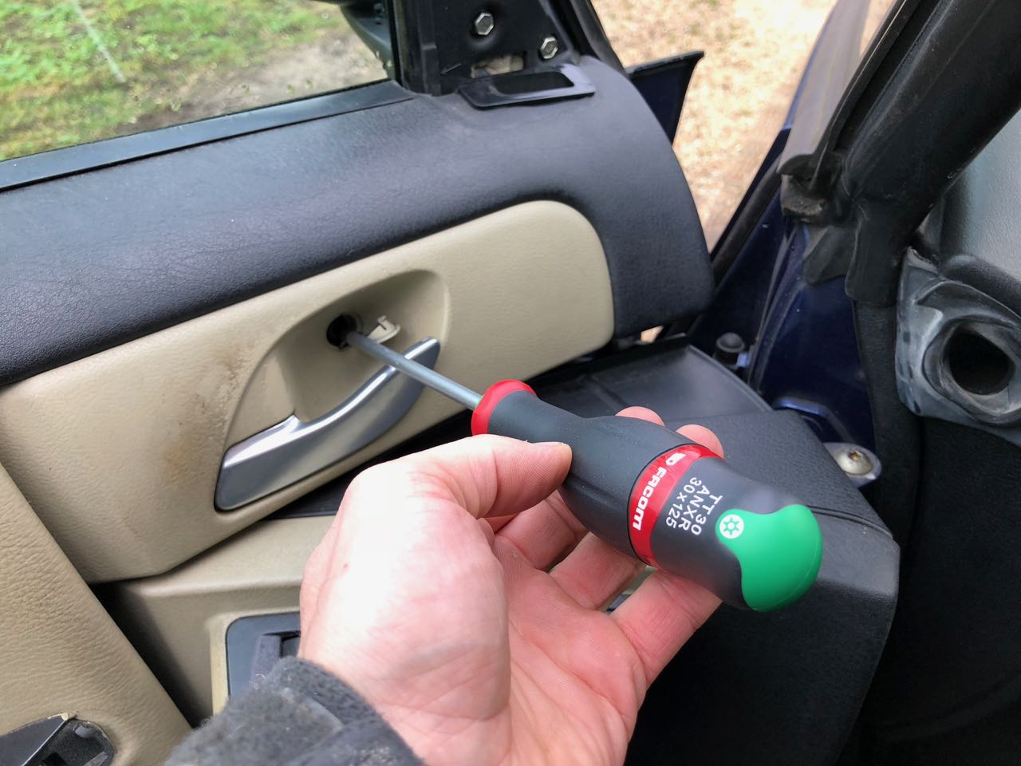
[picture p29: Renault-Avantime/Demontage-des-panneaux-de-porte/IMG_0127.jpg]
Dévisser la vis


Une fois le cache déposé, il faut enlever la vis qui est derrière.

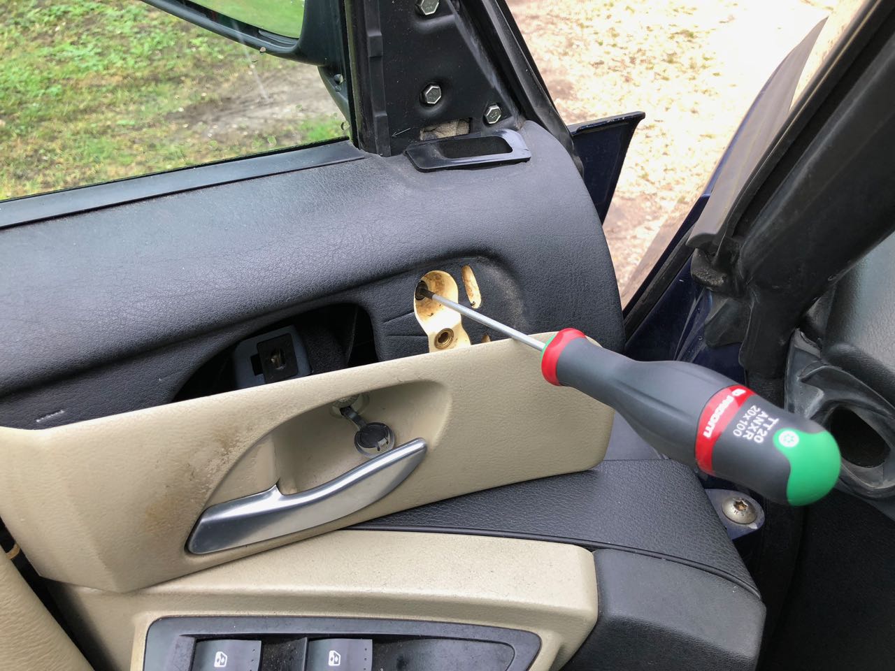
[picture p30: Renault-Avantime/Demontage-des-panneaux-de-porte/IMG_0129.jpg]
Dévisser la vis qui est derrière


### 5. Déposer le séparateur du vide poche

Il y a un cache en plastique à enlever à l'aide d'un gros tournevis plat.

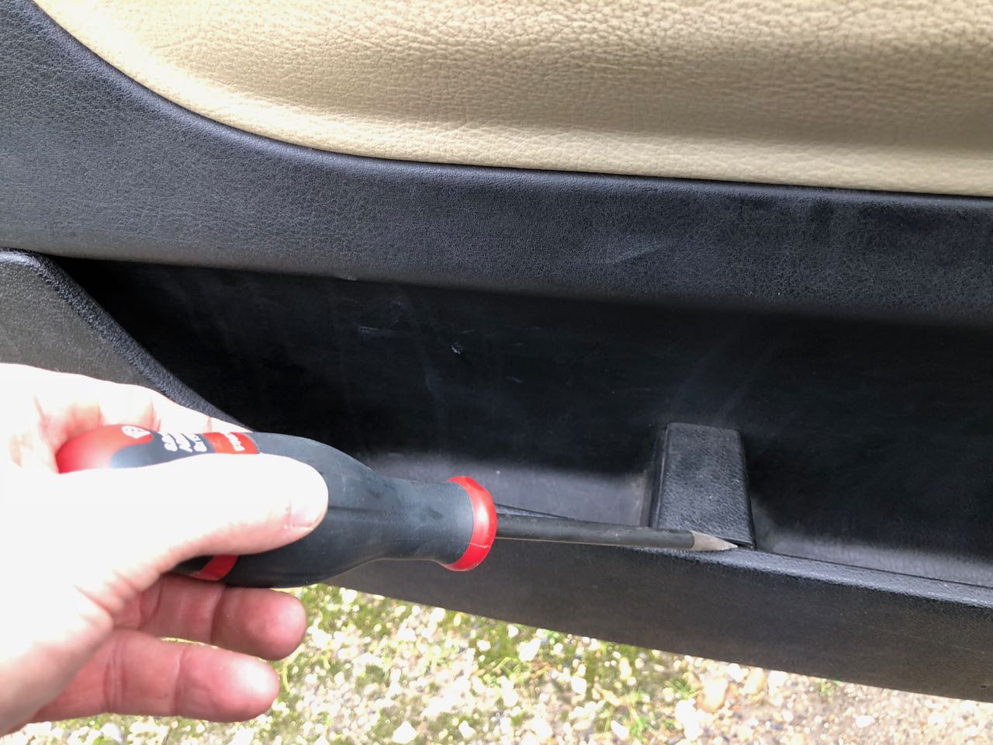
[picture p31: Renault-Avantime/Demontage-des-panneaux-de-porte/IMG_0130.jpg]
Enlever le cache plastique


Une fois le cache enlevé, il faut dévisser la vis qui est au fond.

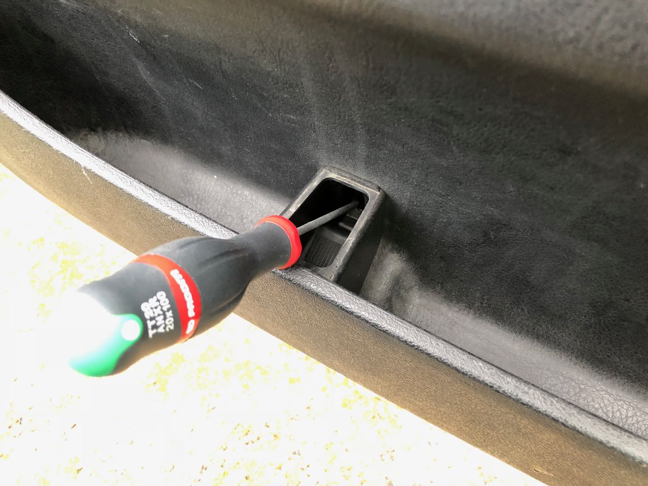
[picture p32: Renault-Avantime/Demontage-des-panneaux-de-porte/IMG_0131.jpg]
Dévisser la vis au fond


### 6. Déposer le panneau de porte

Soulever le panneau de porte et le déposer. Pensez à déconnecter la fiche de l'éclairage.

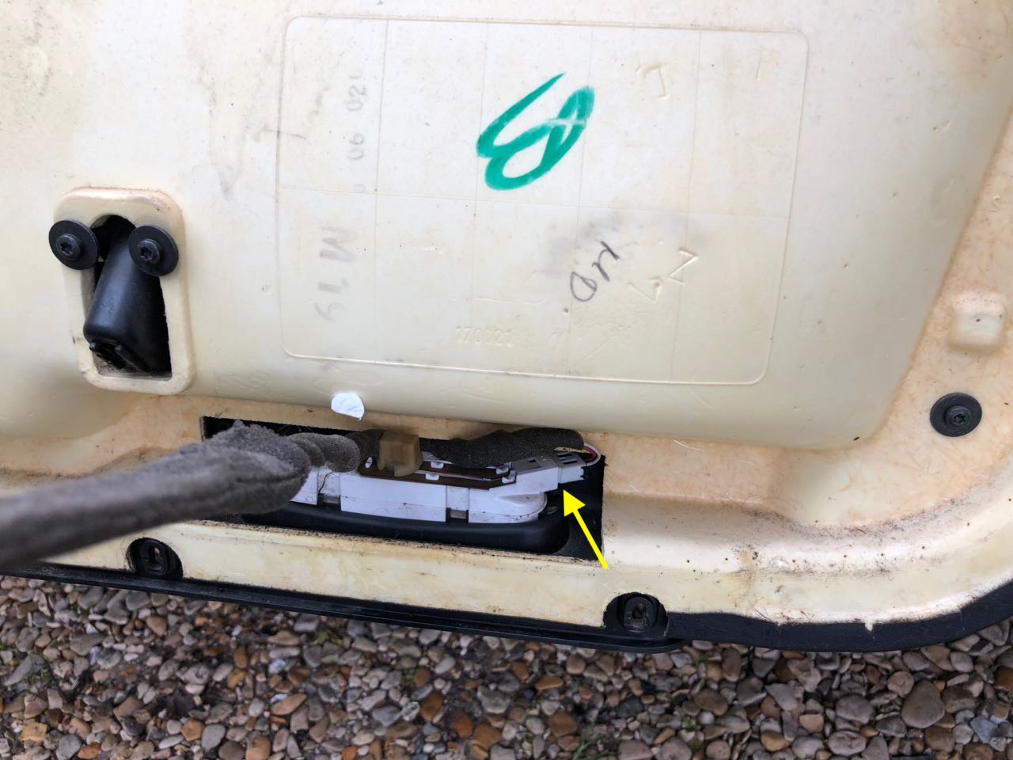
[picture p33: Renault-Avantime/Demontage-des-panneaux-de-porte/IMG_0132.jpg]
Déconnecter la fiche de l'éclairage


### 7. Accès au mécanisme du lève vitre

Enlever les quatre vis de la platine noire et la déposer.

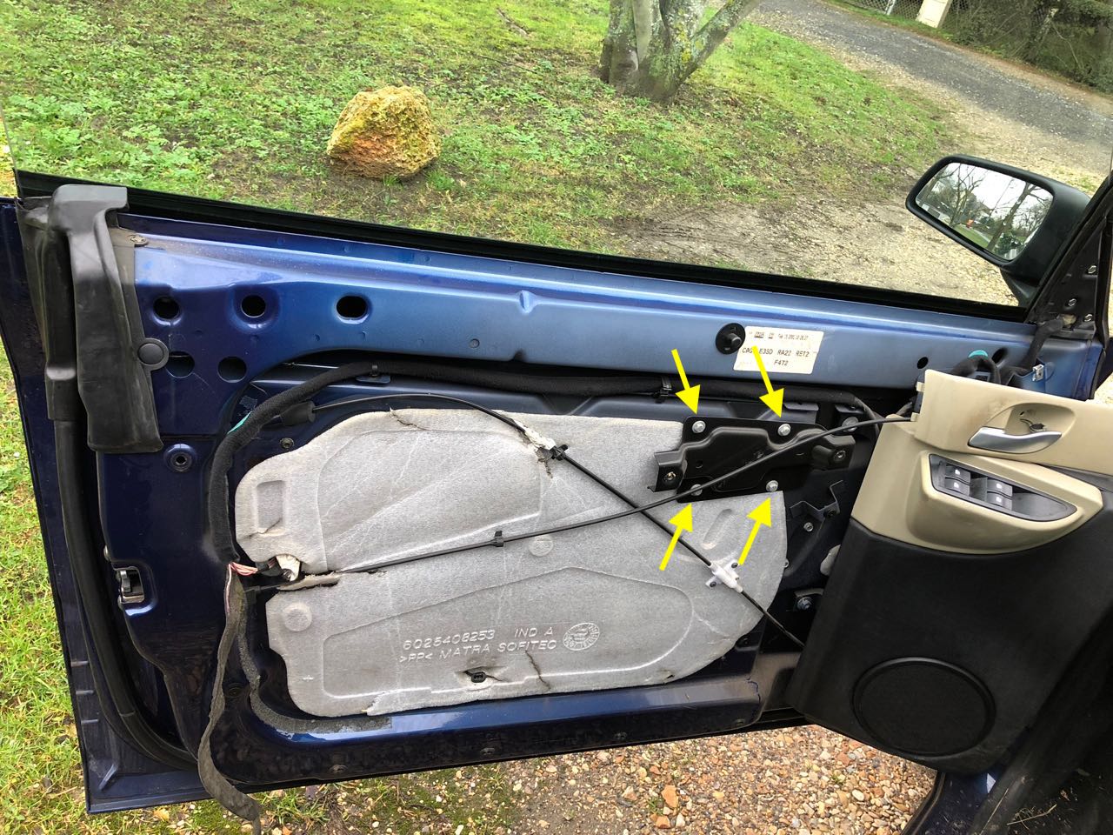
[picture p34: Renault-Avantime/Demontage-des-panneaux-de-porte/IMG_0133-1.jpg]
Déposer les quatre vis et la platine


Déposer les clips et vis qui tiennent les deux cables qui actionnent le verrouillage/déverrouillage des serrures.

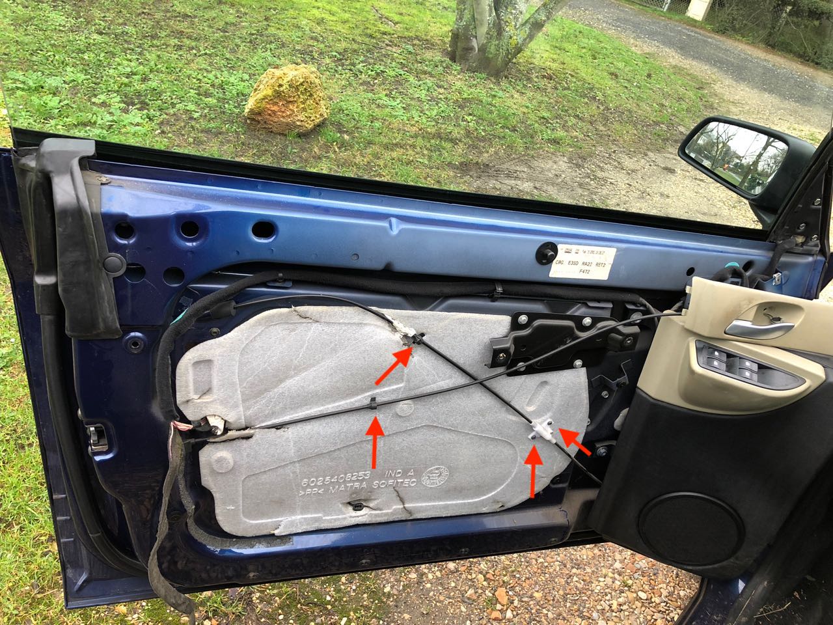
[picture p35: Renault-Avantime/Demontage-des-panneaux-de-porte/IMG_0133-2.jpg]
Déposer les clips et les vis


A l'aide d'une spatule, décoller la feuille de propreté de la portière.
Ne pas abîmer la feuille en polystyrène car idéalement il faudra la reposer !

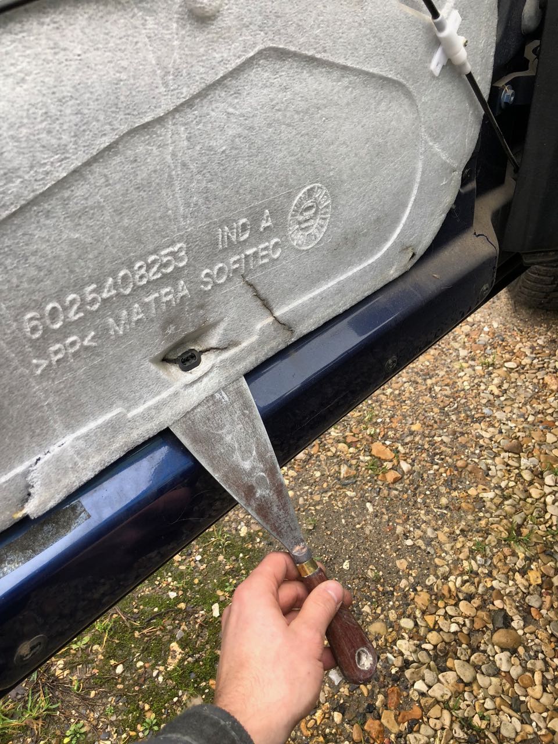
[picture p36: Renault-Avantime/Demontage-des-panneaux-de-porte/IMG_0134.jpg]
Décoller la feuille de polystyrène


## Remontage

TODO

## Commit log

2017-10-29 Remplacement des triangles sur Renault Avantime
2017-10-29 Tableau des couples et illustrations
2017-10-29 correction des fautes d'orthographe
2017-11-01 typo + ne pas oublier de dégraisser les disques de frein
2017-11-01 référence des triangles
2018-01-21 nouveau tuto: démontage des panneaux de porte et réparation de la serrure
2018-01-21 clarté des explications
2018-01-21 plans de la piece
    [piece.skp]
2018-01-21 plans de la piece (correction de l'url)
